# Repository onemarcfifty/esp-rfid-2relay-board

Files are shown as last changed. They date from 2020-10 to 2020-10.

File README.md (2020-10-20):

# esp-rfid-2relay-board
a two relay board for use with esp-rfid and a Wiegand RFID keypad




This is a simple board that I have designed to open my two garage doors. It is using an ESP8266 processor and running the ESP-RFID firmware. Please check the videos on my youtube channel for more details:

[Designing the board](https://youtu.be/ah8-FsuAJAM)
[milling the board with the CNC router](https://youtu.be/63Tgc9mA8FI)

Find more videos on [my youtube channel](https://www.youtube.com/channel/UCG5Ph9Mm6UEQLJJ-kGIC2AQ)

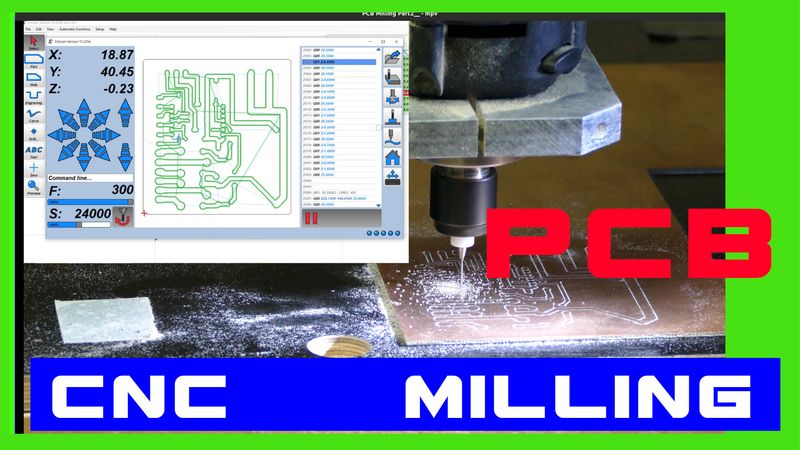
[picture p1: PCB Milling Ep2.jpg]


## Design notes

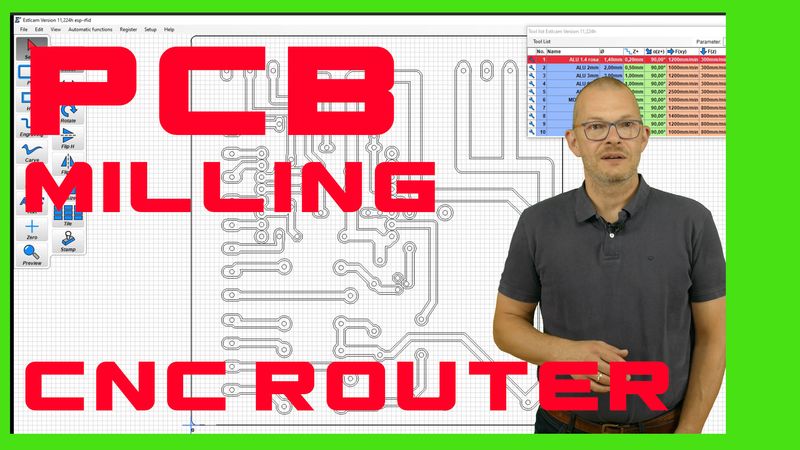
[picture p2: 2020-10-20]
Thumbnail PCB Ep1.jpg

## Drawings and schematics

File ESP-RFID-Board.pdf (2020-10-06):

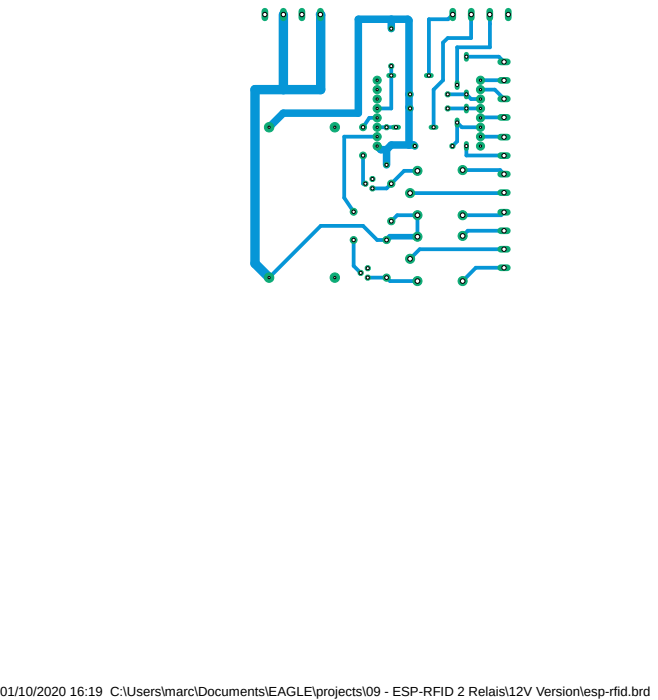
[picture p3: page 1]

01/10/2020 16:19 C:\Users\marc\Documents\EAGLE\projects\09 - ESP-RFID 2 Relais\12V Version\esp-rfid.brd

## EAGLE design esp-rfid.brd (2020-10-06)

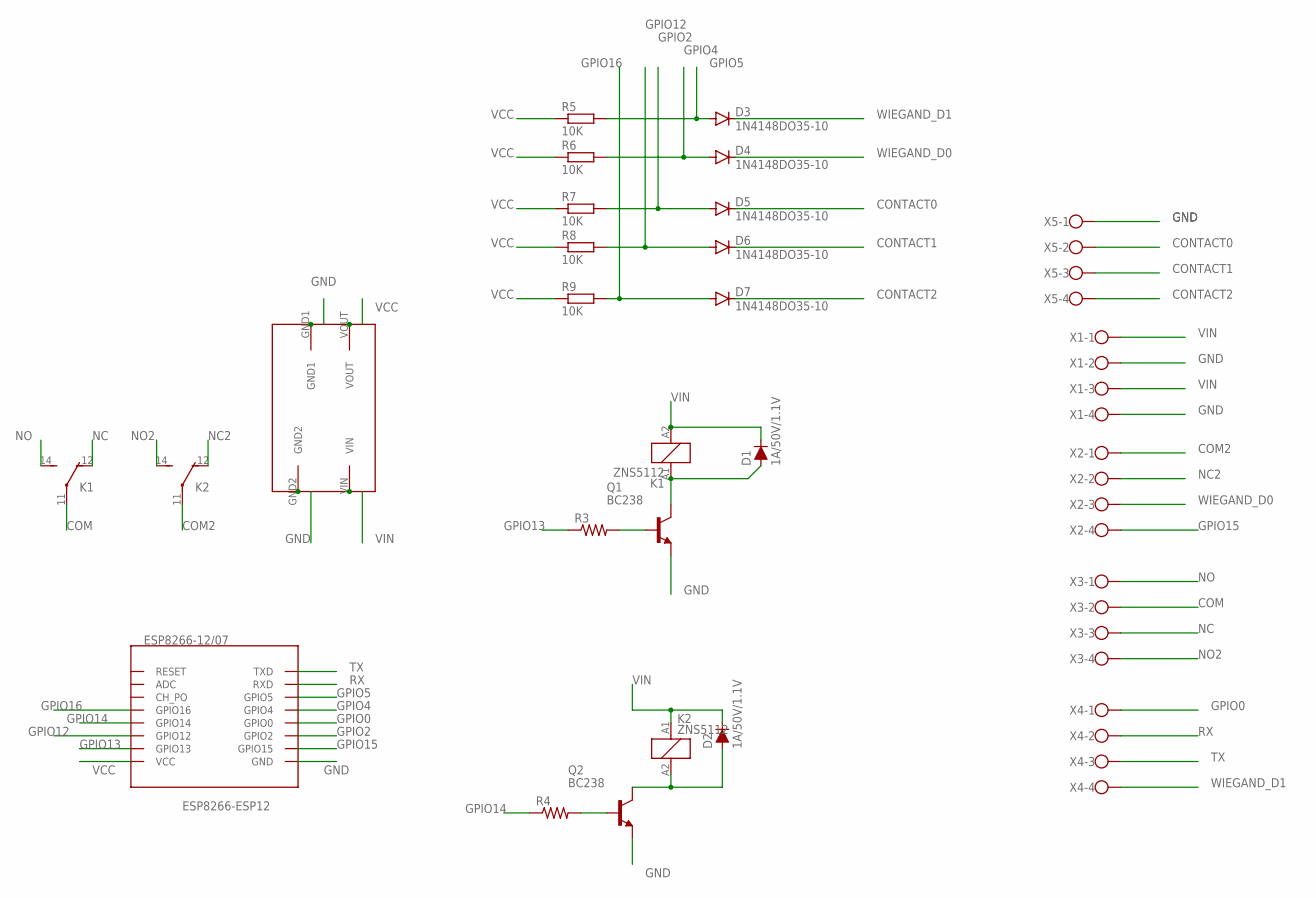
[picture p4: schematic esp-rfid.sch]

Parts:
D1, D2: 1A/50V/1.1V; DIODE-1N4001
D3, D4, D5, D6, D7: 1N4148DO35-10; DO35-10
K1, K2: ZNS5112; ZN5
Q1, Q2: BC238; TO92
R3, R4: AXIAL-0.3
R5, R6, R7, R8, R9: 10K; 0207/10
U$1: ESP8266-ESP12; ESP8266-12
U$2: LM2596-DC-DC-STEPDOWN-BOARD; STEPDOWN-CONVERTER
X1, X2, X3, X4, X5: W237-4

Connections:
COM: K1.11, X3.2
COM2: K2.11, X2.1
CONTACT0: D5.C, X5.2
CONTACT1: D6.C, X5.3
CONTACT2: D7.C, X5.4
GND: Q1.1 (E), Q2.1 (E), U$1.GND, U$2.GND1, U$2.GND2, X1.2, X1.4, X5.1
GPIO0: U$1.IO0 (GPIO0), X4.1
GPIO2: D5.A, R7.2, U$1.IO2 (GPIO2)
GPIO4: D4.A, R6.2, U$1.IO4 (GPIO4)
GPIO5: D3.A, R5.2, U$1.IO5 (GPIO5)
GPIO12: D6.A, R8.2, U$1.IO12 (GPIO12)
GPIO13: R3.P$1 (1), U$1.IO13 (GPIO13)
GPIO14: R4.P$1 (1), U$1.IO14 (GPIO14)
GPIO15: U$1.IO15 (GPIO15), X2.4
GPIO16: D7.A, R9.2, U$1.IO16 (GPIO16)
unnamed: Q2.2 (B), R4.P$2 (2)
unnamed: D1.A, K1.A1 (1), Q1.3 (C)
unnamed: D2.A, K2.A2 (2), Q2.3 (C)
unnamed: Q1.2 (B), R3.P$2 (2)
NC: K1.12 (O), X3.3
NC2: K2.12 (O), X2.2
NO: K1.14 (S), X3.1
NO2: K2.14 (S), X3.4
RX: U$1.RX (RXD), X4.2
TX: U$1.TX (TXD), X4.3
VCC: R5.1, R6.1, R7.1, R8.1, R9.1, U$1.VCC, U$2.VOUT
VIN: D1.C, D2.C, K1.A2 (2), K2.A1 (1), U$2.VIN, X1.1, X1.3
WIEGAND_D0: D4.C, X2.3
WIEGAND_D1: D3.C, X4.4

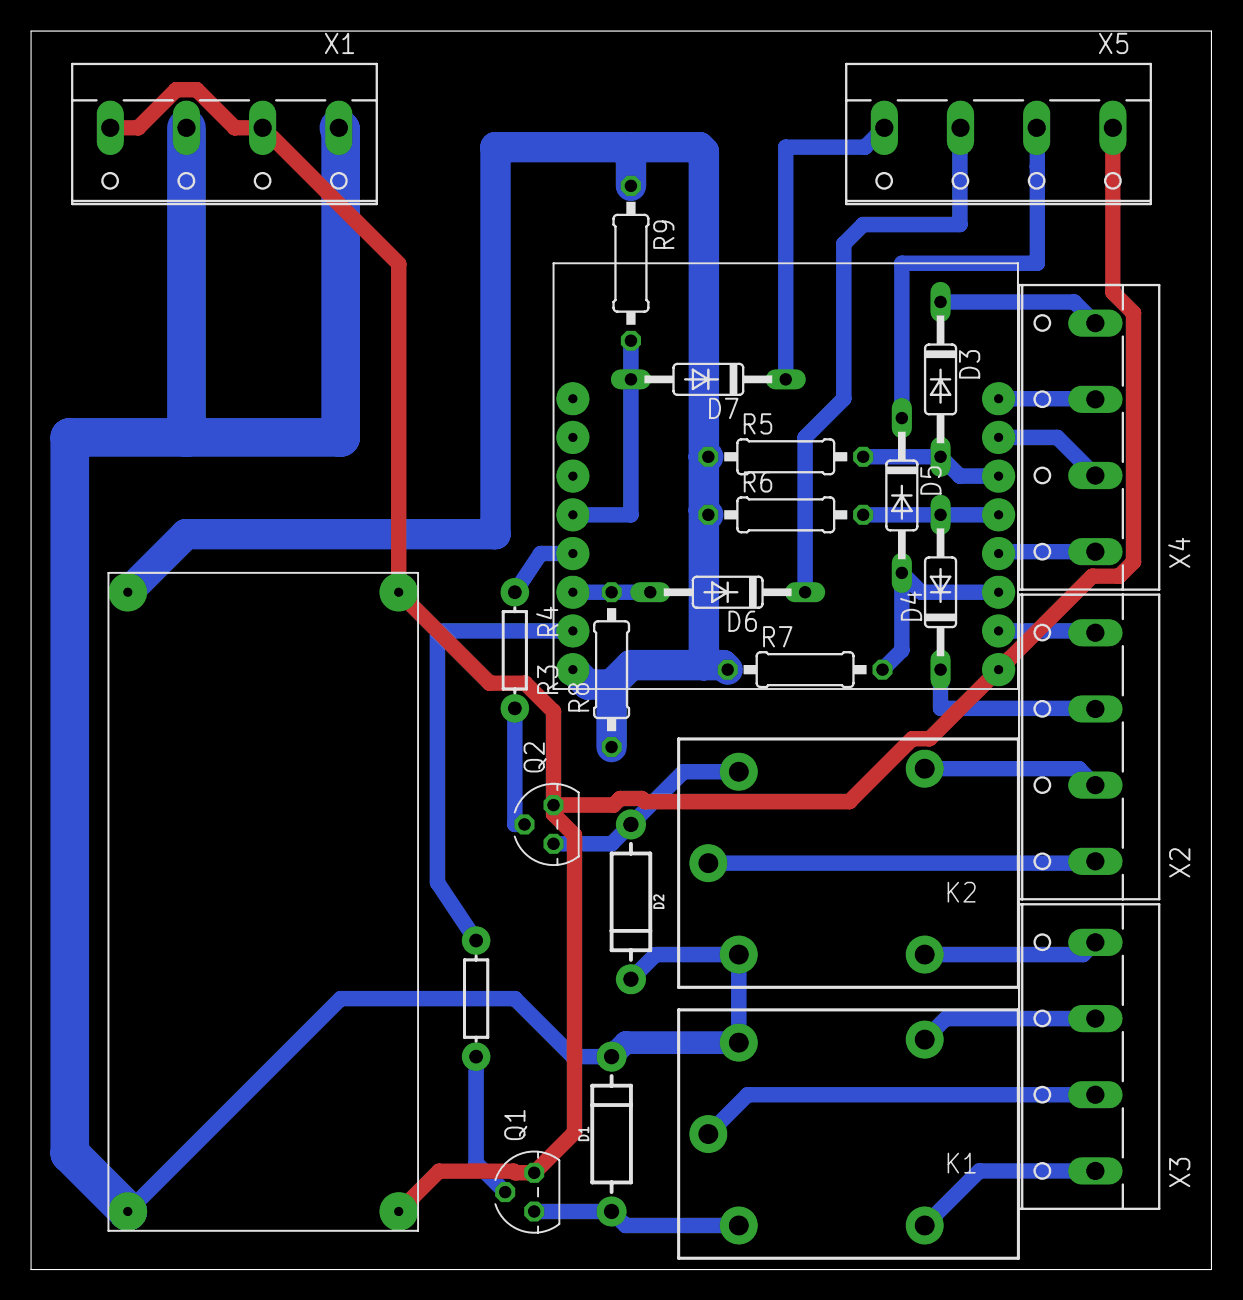
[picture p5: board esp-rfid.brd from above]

Board: 2 copper layers, 77.5 x 81.3 mm, 25 parts (0 on the bottom side), 29 nets.

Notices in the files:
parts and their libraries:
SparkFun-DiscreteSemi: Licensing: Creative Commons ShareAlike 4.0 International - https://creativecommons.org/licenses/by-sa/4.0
